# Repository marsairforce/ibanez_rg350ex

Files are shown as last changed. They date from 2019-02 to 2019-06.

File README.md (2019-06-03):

# Ibanez RG350EX

An Ibanez RG350EX with Seymour Duncan Invader pickups and custom wiring.

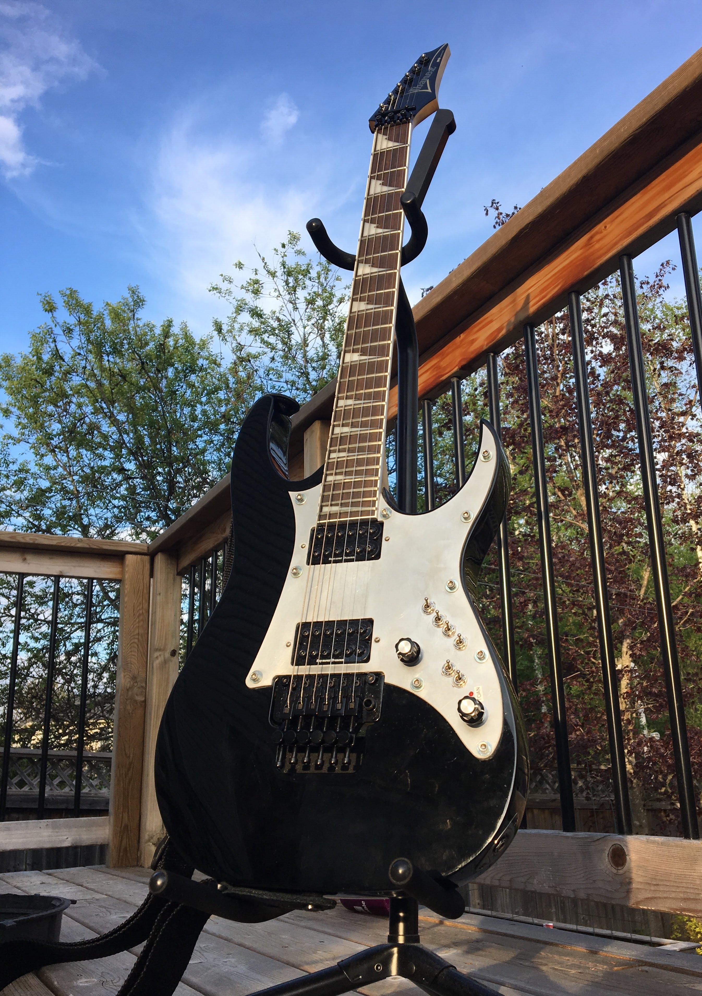
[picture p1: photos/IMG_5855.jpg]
guitar


These switches allow for me to have 20 different configurations of the two pickups

* Just one pickup
* Both pickups, in series or parallel
* Phase reversing of the pickups
* Coil splitting (series or parallel)

I posted this in hopes it will be interesting or thought provoking to other musicians. And to welcome feedback for ideas to improve things.

If anything else an instruction manual for myself so I can always remember how my guitar works.

## Background

I got this in 2009 from Fleet Pro sound. I think for what ever reason I was missing my Mexican Strat after I sold it before moving back to Winnipeg following the intern at Nortel. By now I was back in Ottawa and had wanted to get back into Guitar.

I tried to get into playing it but it sounded terrible.

So it sat in the furnace room for like a decade.

Now I brought it out, changed the pickups and the wiring and it is awesome again.

## Switch Function

There are eight switches on the control panel.

Seven of the switches work to change the pickup configuration.

The eigth switch is a cut out for the tone circuit.

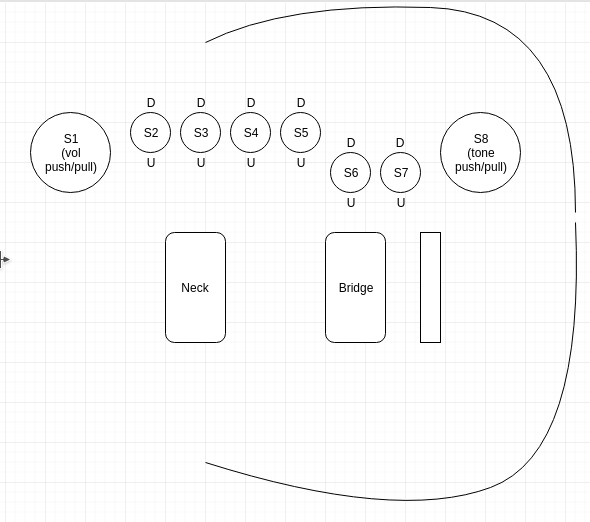
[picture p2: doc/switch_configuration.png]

(diagram not to scale)

* six toggle switches.
* two push pull switches on the potentiometers.

Table 1 below explains what each switch does.

| Switch | Description | Up | Down |
|:---|:---|:---|:-----|
| S1 | Phase invert bridge pickup | Neck pickup phase is inverted from the bridge pickup | Neck pickup phase is the same as the bridge pickup |
| S2 | Neck pickup high side | Connected to bridge low side | Connected to output
| S3 | Neck pickup low side | Connected to bridge high side | Connected to ground
| S4 | Bridge pickup high side | Connected to neck pickup low side | Connected to output |
| S5 | Bridge pickup low side | Connected to neck pickup high side | Connected to ground |
| S6 | Neck coil split | Nck pickup in series (humbuck) mode | Neck pickup in single (parallel) coil mode |
| S7 | Bridge coil split | Bridge pickup in series (humbuck) mode | Bridge pickup in single (parallel) coil mode |

And table 2 below explains the modes

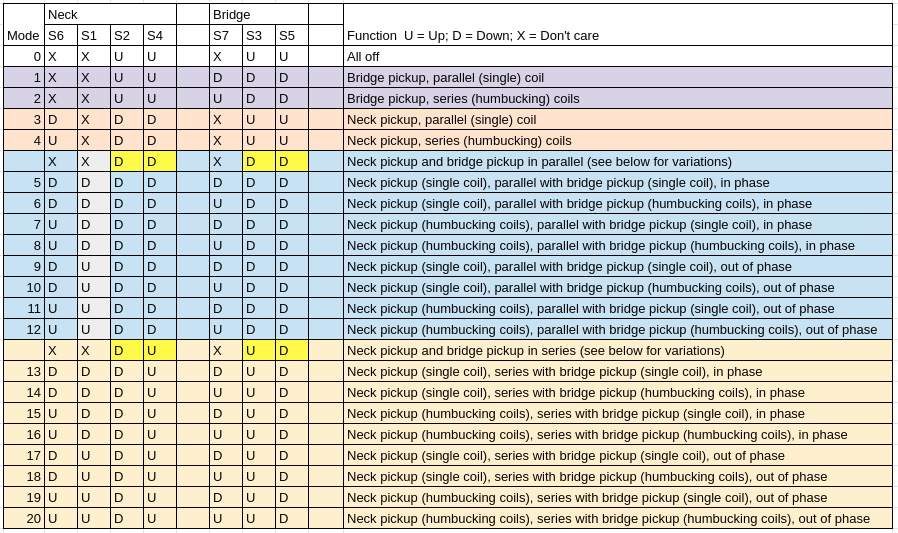
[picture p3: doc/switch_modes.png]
table 2


There are 20 tone possibilities.

> This does not include the other permutation of having the pickups in series. The setup shown here with [S2, S4, S3, S5] i [D, U, U, D] has the bridge pickup connecting to the the output jack, then to the neck pickup, then to the ground.
>
> If we had [S2, S4, S3, S5] as [U, D, D, U] that would connect the bridge pickup to the output jack, then to the neck pickup, then to ground.
>
> However this is tonally identical, so the permutation was omitted.

## Schematic

For those interested.

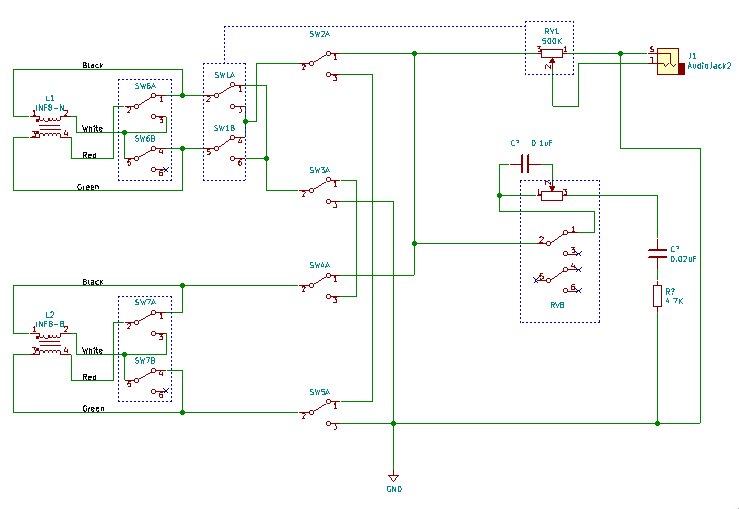
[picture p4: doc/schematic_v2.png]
schematic


The function of series/parallel for the pickups is done with S2, S3, S4, and S5. These are DPDT toggle switches, but I am only using 1 pole on each switch.

> This was just my idea for how to make two pick ups be
>
> * none
> * just one
> * just the other
> * both in parallel
> * both in series
>
> If you have any ideas for how I could do this better I am excited to learn.

The S6 and S7 used to be phase control switches. Where each pickup went into these to reverse the phase. I later realized that with only two pickups I do not require two switches. This was because my previous guitar had three pickups and I put in three phase switches, one for each pick up. But here with two pickups, if I move both switches the pick ups are just back in phase with each other again. So if I have only one switch then the pick ups will be out of phase, and it does not matter which pick up is the out of phase one. I moved the phase control switch to the S1 (the push/pull switch in the volume pot) and made these S6 and S7 be the coil split controls for each pickup.

I do not actually split the coils, just follow the Seymour Duncan wiring guide for series / parallel. Basically the white and red wires are not hard soldered to each other, but to the switch.

I wired the tone circuit to be a grease bucket tone mod (search the Internet). The S8 is not really needed if we crank the tone knob all the way off I find. I might rewire this later to do something else.

## Application

Some practical tone settings that are similar to other guitars or styles of playing.

| Mode | S1 | S2 | S3 | S4 | S5 | S6 | S7 | Notes |
|:---|:--:|:--:|:--:|:--:|:--:|:--:|:--:|:---|
| A Stratocaster sound | D  | U  | D  | D  | D  | D  | D  | Just the bridge pick up, single coil mode |
| A Telecaster sound | D  | D  | U  | D  | D  | D  | D  | Just the neck pickup, single coil mode |
| Heavy and Loud | D  | D  | U  | U  | D  | U  | U  | Both pickups in humbuck mode and series |

I will expand the "sounds like a " table as I play with it more.

## Waveform Analysis

Hooking the guitar directly up to an oscilloscope.
Trying to strike the low E string the same way each time.

## Single Pickup

The main difference here is changing the single coil to double coils

| Pickup | Single coil | Humbucking | Change |
|:-----|:---|:---|:--|
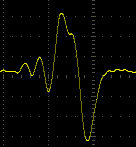
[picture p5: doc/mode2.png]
mode2
| **Bridge** | mode1 |  | S7 |
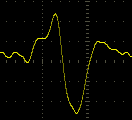
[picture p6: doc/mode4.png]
mode4
| **Neck** | mode3 |  | S6 |

## Pickups in Parallel

| Phase | Neck (S) Bridge (S) | Neck (S) Bridge (H) | Neck (H) Bridge (S) | Neck (H) Bridge (H) |
|:-|:-|:-|:-|:-|
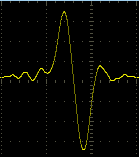
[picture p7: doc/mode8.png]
mode8
| **In Phase** | mode5 | mode6 | mode7 |  |
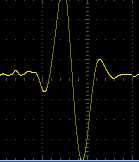
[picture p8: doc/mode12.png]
mode12
| **Out Phase** | mode9 | mode10 | mode11 |  |

## Pickups in Series

| Phase | Neck (S) Bridge (S) | Neck (S) Bridge (H) | Neck (H) Bridge (S) | Neck (H) Bridge (H) |
|:-|:-|:-|:-|:-|
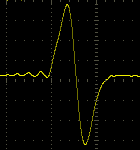
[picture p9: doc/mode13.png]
mode13
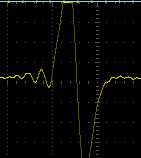
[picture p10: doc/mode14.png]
mode14
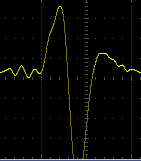
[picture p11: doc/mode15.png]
mode15
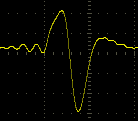
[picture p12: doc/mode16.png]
mode16
| **In Phase** |  |  |  |  |
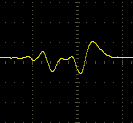
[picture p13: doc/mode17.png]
mode17
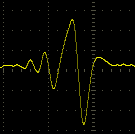
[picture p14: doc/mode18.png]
mode18
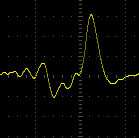
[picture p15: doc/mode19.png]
mode19
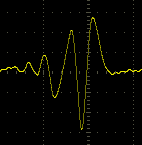
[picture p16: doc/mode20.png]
mode12
| **Out Phase** |  |  |  |  |

## Custom Aluminum Pick Guard

I removed the middle pick up. I did not have any use for it. This left a hole where the pick up used to be. I tried covering it with shiny furnace pipe tape. And later a piece of a CD-ROM. But no matter what i did it looked pretty Ghetto.

If I could have built a sustainer pickup it would have fit nicely into the slot. But I have not been able to overcome several technical challenges of making this work. Mostly the magnetic fields from the coil in middle position interfere with the other pickups.

So I took the plastic pick guard to a water jet cutting place in town and had them make me a pick guard out of 1/8" aluminum. It had the same holes as the switch configurations from before too.

I attached the pick guard using some hex cap machine bolts that attach to wood screw ancher nuts in the body. I had to drill out a larger hole to screw the nuts into the body.

I liked the effect so much I went and modified my Fender Squire bass to be the same as well. I don't have a project for the bass, it just follows the evolution of the guitar.

The result is something I think is very visually stunning but also provides a bit more of a resonance to the sound of the guitar, I think anyway.

## Clean Boost Circuit

I built a clean boost based on the TL071 op-amp inside the guitar.

It is powered by a stereo jack. The ring connector on the TRS connector can supply 9V into the guitar. An internal DC-DC converter steps it up to 12V. The gain is fixed to be just about 1:1.

The motivation here is not to produce a louder output, but to convert the high impedence from the pickups into a low impedence signal to drive over the patchcord.

Even with the 20 foot patch cord I regularly use I can slightly hear a difference with the tonal quality and the sustain of some higher pitched notes when using the clean boost vs not using the clean boost.

The clean boost circuit facilitated upgrading the jack connector. I got a really good Switchcraft model. Which randomly did not come with the mounting hardware. A trip to the hardware store found some more special ass nut to fit it. And then more drilling to make it fit. The jack now holds the patch cord very well. And being fully shielded is less interface to pick up noise like the old one was.

## Locking tuners

I replaced the stock tuners with locking tuners. These allow me to wind the strings a little easier without needing to wind the string around a bunch of times. I don't really need them with the locking nut, but I was curious what they were about. I also wanted to replace the standard tuners because several of them had a lot of random backlash and that made tuning somewhat challenging.

## Actual Floyd Rose Trem

I got tired of the shitty edge trem. The tremmolo bar was so loose it was not even useable. The shitty zinc block under it was not very tonally pleasing to me. And the edges of the metal of the bridge against the posts were all shitty and worn in. Because its a shitty bridge.

The actual floyd rose trem has a good feel to it, I think. I got the fat brass sustain block to go with it, so more of a different sound from that as well. I first ordered the 37mm block, but it was just a bit too big to allow me to ge the back cover onto the guitar, and would touch your body as you played. I later ordered a 32mm block.

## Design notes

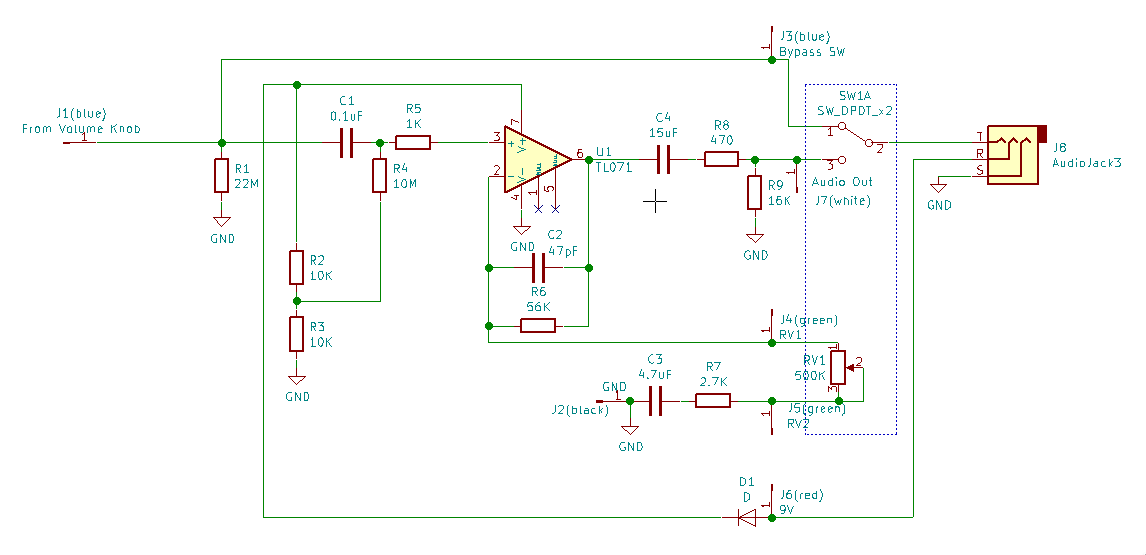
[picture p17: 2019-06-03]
doc/preamp_schematic_v1.png

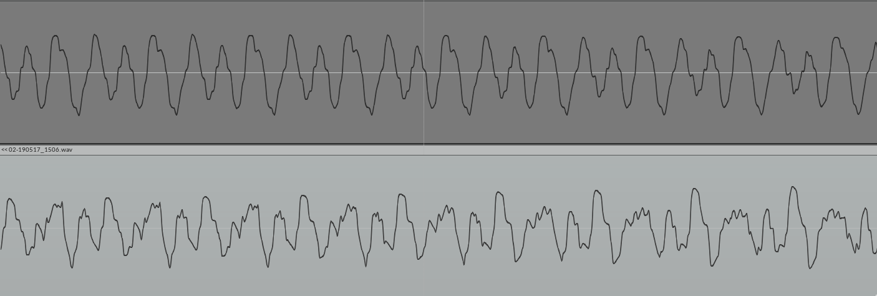
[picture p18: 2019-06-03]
photos/open_d_string_without_and_with_boost.png

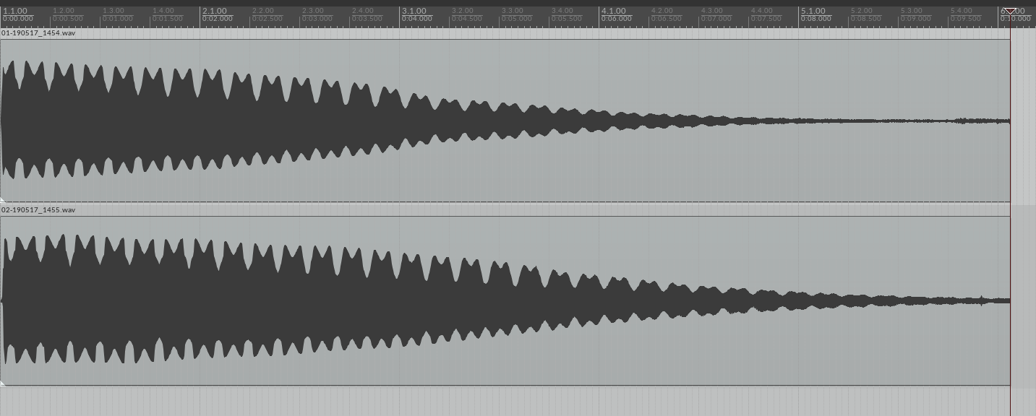
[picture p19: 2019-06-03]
photos/high_e_harmonic_without_and_with_boost_circuit.png

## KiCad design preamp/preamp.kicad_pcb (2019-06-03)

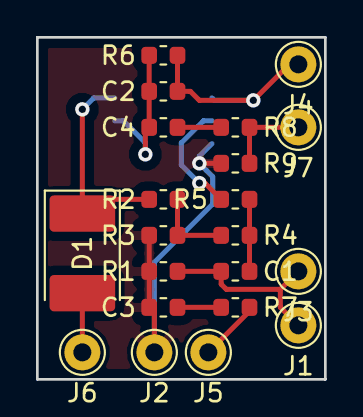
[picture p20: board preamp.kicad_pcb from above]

Board: 2 copper layers, 16.0 x 19.0 mm, 22 parts (1 on the bottom side), 13 nets.

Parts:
C1: 0.1uF; C_0603_1608Metric
C2: 47pF; C_0603_1608Metric
C3: 4.7uF; C_0603_1608Metric
C4: 15uF; C_0603_1608Metric
D1: D; D_2114_3652Metric_Castellated
J1: From Volume Knob; Pin_D1.0mm_L10.0mm
J2: GND; Pin_D1.0mm_L10.0mm
J3: Bypass SW; Pin_D1.0mm_L10.0mm
J4: RV1; Pin_D1.0mm_L10.0mm
J5: RV2; Pin_D1.0mm_L10.0mm
J6: 9V; Pin_D1.0mm_L10.0mm
J7: Audio Out; Pin_D1.0mm_L10.0mm
R1: 22M; R_0603_1608Metric
R2, R3: 100K; R_0603_1608Metric
R4: 10M; R_0603_1608Metric
R5: 1K; R_0603_1608Metric
R6: 56K; R_0603_1608Metric
R7: 2.7K; R_0603_1608Metric
R8: 470; R_0603_1608Metric
R9: 16K; R_0603_1608Metric
U1: TL071; SOIC-8_3.9x4.9mm_P1.27mm

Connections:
GND: C3.2, J2.1, R1.2, R3.2, R9.2, U1.4
unnamed: C1.1, R4.1, R5.2
unnamed: C1.2, J1.1, J3.1, R1.1
unnamed: C2.1, C4.2, R6.1, U1.6
unnamed: C2.2, J4.1, R6.2, U1.2
unnamed: C3.1, R7.2
unnamed: C4.1, R8.2
unnamed: D1.1, R2.1, U1.7
unnamed: D1.2, J6.1
unnamed: J5.1, R7.1
unnamed: J7.1, R8.1, R9.1
unnamed: R2.2, R3.1, R4.2
unnamed: R5.1, U1.3

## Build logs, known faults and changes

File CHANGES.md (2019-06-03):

# Change log

## 2019-05-15

The circuit boards for the boost circuit came in the mail. Assemble these. Put it into the guitar. Build the power junction box pedal.

So far testing it seems to work well as far as a clean boost goes. Will continue to do analysis for how differnt it sounds. Or what it can do to kick up other pedals. I am able to turn the clean channel of my H&K amp crunchy with it. So it is already a lot of possibilities. Did some quick on/off tests by playing a string and then having Reaper record the track. Then look at the waveform. I can see some higher frequency components in the signal. And the sustain seems to be a bit longer and not taper off as quickly.

## 2019-05-08

The pick guards were ready and the Floyd rose trem came in. Spend the evening assembling the guitar. The holes on the pick guard did not exactly line up with where the wood nuts. I blame the imprecise wood and how I drilled the holes. The hardest part was changing the bridge posts. Get it all back together. It feels nice and new and different. I was thinking to wait until the circuit boards for the preamp came in but I wanted to try it out.

Sounds different too with 10-46 strings on it too. Took a few attempts to set it up and adjust the action. I was able to remove the shim I put in the neck before.
Still feels a bit high but it is better than it was I think.

## 2019-05-01

Took apart a MXR clean boost pedal. Was thinking, I could just build this into the guitar. So that there is the low impedence output to not lose high ends.

But this circuit board is very large. And most of it is for the jacks for connecting the cables. And then the big dumb bypass switch. And really this is just an opamp circuit with a potentiometer.  Looking up on the interwebs. This uses the TL071 or [TL061](https://www.electrosmash.com/images/tech/microamp/mxr-microamp-schematic.png) even. And this board is all discrete thru hole parts. Manufactured in 2006. I have a surface mount TI087 op amps. And some of these parts.

Draw up the schematic in kicad. Lay out a board. Order the board from OSHPark and resistors and capacitors from DigiKey. It was an entire evening of fun to draw up and lay out a PCB. It cost me about $130, but parts for 6 circuit boards plyus stock. It is basically $25 each to make. The board is about 3/4 inch square and all surface mount 0603 parts plus the op-amp (soic-8). So it should have no problems wiring it into the guitar. I did not bother with mounting holes or slots. Just large pads for the wires to go onto. I can like wrap it in electrical tape or something.

I was thinking to use the ring connector on the input jack to feed power into the guitar. And replace the tone knob pot and push/pull switch to be the power and bypass for the preamp. I can use external pedals to shape the tone. I will need a box to connect the stereo patch cord to to break out the signal. Power jack in, cable to guitar, and audio out. I guess as the need evolves I could build some kind of active filter or EQ or effect into this box too. But for now a simple junction box is good.

This way it is possible to still use it as a regular guitar. And I don't have to mess around with batteries in the guitar. Since I'll have a few of them I can put one in the bass too. Though not sure I even need it there. The bass is pretty responsive as it is and I only usually use it for clean tone. Looking to get a different kind of overdriven sound with the boost and low impedance output from the guitar.

But for now waiting for the circuit boards to be made and the parts to come in.

Preamp schematic and board is a folder in this project.

## 2019-04-28

Ordered locking tuners. I was tired with the A string tuner having so much backlash. Just new machine heads would be ok, But these were on sale on Amazon. I am stil mad at amazon for their shipping and wanting you to sign up for amazon prime thing they try to bully me into having it come sooner if I sign up, but then if I don't it takes like a lot longer conspiciously.  But it was on sale.

Had to drill small hole. I measured and drilled the hole and then found the template on the packaging. Doh. Oh well. They look good and straight.

I didn't test them out becuase the guitar is currently all apart waiting for the new pick guard to come in.

## 2019-04-22

I tried cutting the sheet metal I picked up. But it was too thin and was bending and getting scratched up from the saw vibrating over it.  I am sure I could file the edges to be smooth, but the amount of bending was likely not easy to fix. The metal is just too thin. It is like furnace pipe material and bends and looks bad.

Go by a sheet metal place, pick up an end cut piece of 1/8 inch thick sheet. Trace the pick guard on paper and take it to a water jet cutting place. Since the cost is mostly for the set up in CAD they will be able to make me a couple of them from the amount of metal I gave them. I decided to upgrade the bass guitar pick guard as well. So they will match. Also hoping the metal shielding will reduce some of the buzz I get from the not double coil pick up on the bass. They said it would be a couple weeks. Waiting for these to get back.

## 2019-04-21

I got tired of having the hole where the middle pickup used to be. I had glued a piece of cdrom to cover the hole, but that was high enough up the pick would sometimes hit against it. So removed it. But now its the ugly hole.

I had the idea, why have a piece of plastic that tries to look like an aluminum pick guard when I can just have a piece of aluminum.

I had the idea to instead of use the screws into wood to place some wood slot screws and machine cap head screws to hold it down.

Stopped by Ottawa fastners store on the way home to get some bolts and hardware. And a piece of aluminum.

I went by Canadian tire, they had a welding steel plate a little bit thicker than the aluminum. I figure I will try the aluminum first, since it will maintain its shiny properties. But if it is too thing and looks all bendy I can then try the steel.

Pick up a set of step drill bits from Lowes. These will make a much better hole than the regular bits I have. Which totally suck for drilling sheet metal (makes the holes all bent and deformed)

I didn't even own a jigsaw. Get one from Hardware. And a sheet metal cutting blade.

So as usual the influx of tools needed to help me do this was a lot more than the materials. But these are generally useful for other hobbies.

And my next challenge is having time to play with the saw to cut metal. Work all day, kids all evening, and then kids in bed. Tracing the pattern was easy enough. Use the old pick guard but don't trace out the middle pickup hole.

I noticed before the bridge pickup, the pole pieces are not really under the strings. The pickup is a bit wider for this floyd rose copy bridge. So have the idea I can cut a bridge pickup hole on a bit of an angle, to try to get some more pole pieces under the strings. But then to make this lined up with it all apart might be challenging. But also no the pickup is narrower than the strings into my bridge, so making it on an angle would make the pickup cover less than it does now.

Unrelated last week I ordered a new actual floyd rose trem. I wanted to see what actual metal would work like, since the knife edge on this bridge is already flattened out so it is not returning to its original spot after touching the trem. And the trem bar has so much backlash (loose) it is not really usable. I found out how to better tighten it after I took it all the way out, but I am still fed up with this trem. The metal is all chipeed. It is basically paint over some kind of shitty die cast zinc metal. Where the official floyd rose trem has the brass block. I ordered the fat brass sustain block, 37mm. But now I have anxiety that might be too long/deep to fit into my guitar body. And the way the wood is on the back it might require me to lose the back plate. Shrug I guess. But these have not come in yet. Maybe I should do a wait and see for the carving the bridge pickup hole to make sure I can fit the new bridge properly.

Having some back burner thoughts about putting a valve preamp into the guitar. Would need to solve the problem of getting a DC power supply into the guitar. And then a high voltage supply for the tube, and then perhaps gain control for each pickup. We have two elements in the 12AX7B, one for each pickup. But then we need the special power box adapter to use the guitar. And we have to worry about microphonics with the tube inside the guitar as we play it. Though we do solve the frequency loss by making the output of the guitar a lower impedance output, would not need the tone control in the guitar. Would probably want to have a fallback mode to use it regularly, or have a different connector for the line out. Really it is perhaps more practical to use a solid state JFET based preamp. But, tubes are just so awesome. Just idle thinking now.

## 2019-02-20

Push pull pots arrived. Install them.

* One is push pull for the phase switch.
* Other is for tone control enable/disable (though it doesn't seem to be noticable if i dial tone all the way over).
* The old phase change toggle switches are now coil series / parallel switches. I followed their [diagram](https://www.seymourduncan.com/wp-content/uploads/2016/05/WD_Pushpull_minitoggle_3.pdf)

Apply some linseed oil to the fretboard. Clean it up pretty good. It looks great now.

New strings, Ernie ball super slinky. Sound really great.

## 2019-02-17

Order two new potentiometers from DigiKey. The volume pot feels scratchy and hard to turn lately. Probably it is cheap and breaking on me.

* Wanting to have a push/pull switch on the tone knob to have it disconnect itself all together.
* Wanting to remove the phase reverse switches. With only 2 pickups one will always be out of phase with the other one. we need to have just one phase control switch then. Maybe consider removing the phase control switches and using a switch under the volume pot to push/pull to invert the phase of the bridge pickup. Though at the moment I do not have a need for 2 switches, and not wanting to remove the switches and leave holes. And not wanting to rewire things unless I need to
* I don't think I want to get into coil splitting at this time. But having the extra switch would let me do that too.
* Watch some more youtube. Ok, doing a series/parallel wiring would be good for changing the tone. And freeing up these 2 toggle switches from the phase shift and using a push pull knob switch for that should be good. And then toggle switches as https://www.seymourduncan.com/wp-content/uploads/2016/05/WD_Pushpull_minitoggle_3.pdf

## 2019-02-14

Order the SH8 neck pickup for Valentines day present. Put it in. Sounds great. That old pickup was a piece of shit. I took it apart. It was made like a piece of shit. No wonder things sounded bad.

Get distracted trying to design some kind of setup for a sustainer pickup. An 8 ohm coil to resonate the strings with fluctuating magnetic fields. Perhaps partly because the new good pickup has more magnetic draw on the strings so the sustain now behaves a bit differently.

Spend the long weekend into Family day trying various iterations of differnt coil designs. I don't seem to have the magic wire gauge to make a coil that is powerful enough within the right impedance and form factor that would fit into the guitar after anyway.

More importantly. Looking into the couple of existing sustainer type products. They seem to be a neck configuration and bridge pickup. This is probably by desing for two reasons.

* resonating in the neck pickup position requires less energy to do so, because it is closer to the mid point of the string, not the mid pickup closer to the edge anyway.
* The resonator coil spits out a ton of garbage magnetic interference that the other pickups read. This causes horrible feedback and high speed oscillations. Maybe this is a shitty problem with the shitty simple amplifier circuit I am testing the coil with.

But sort of now having the feeling if I want to get into a sustainer pickup, i really should just concede and buy a pick up. but then that means I would likely want to buy a cheap guitar to go with it. Since not using the nice awesome Seymour Duncan Pickups I just worked so hard to put into this guitar is not something I want to do.  Physically I don't know how to create a pickup to fit in the mid pickup slot that would have enough power to resonate the strings, that would not interfere with the ohter pickups.

### 2019-01

Cleaning the desk the baby found a plastic bin of the parts I took out from the guitar. It was one of those forgotten desk time capsules. And then the "oh yea. that".  This year I have been getting back to my classic hobbies. Finding myself again. More stuff working on the computer. More thoughtful appreciation of my hobbies. Feeling like I want to get back into playing guitar again too.

Order a Seymour Duncan Invader SH8 bridge pickup from Amazon. Put it in. Oh my gawd it sounds so much better.

Come up with the wiring for the switches to select the bridge and neck pick ups. Try to remember what I had done before. Only here instead of three pickups I only want to work with two. Order switches from digikey.

Read up on how tone knobs work. I have one there. Might as well try to use it.  Learn about treble bleed tone control circuit and wire this up with the rubbish capacitors I have in stock.

The new pickup and switches are awesome. I like having a tone control again.  Though I find any combination of using the neck pickup in the circuit makes the sound output sound like shit.  Contemplating just removing everything, use a single pick up and volume knob. Like how Eddie Van Halen did on his Jackson guitar for the "Franken Strat" build. Minimal and simplicity.

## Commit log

2019-02-19 create schematic for wiring
    [ibanez.sch]
2019-02-21 Update schematic following coil split switch mod
    [ibanez.sch]
2019-02-21 Add link to wiring diagram for series/parallel switch
2019-02-25 update schematic. add pictures
    [ibanez.sch]
2019-02-25 replace switch functions with markdown table.
2019-05-03 local mods, was updating wiring
    [ibanez.sch]
2019-05-03 create a preamp module
    [preamp.kicad_pcb, preamp.sch]
2019-06-03 preamp module
    [preamp.kicad_pcb, preamp.sch]
